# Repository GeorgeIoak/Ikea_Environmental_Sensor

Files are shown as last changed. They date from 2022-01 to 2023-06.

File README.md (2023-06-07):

# Ikea_Environmental_Sensor
Replacement Board for [Ikea Vindriktning PM2.5 Sensor](https://www.ikea.com/us/en/p/vindriktning-air-quality-sensor-60515911/)

## This board is meant as a complete replacement for the board rather than adding in a new board. 

## This board will add the following:

- ESP32-C3 processor with onboard antenna
- [Sensirion SGP40 VOC Sensor](https://www.sensirion.com/en/environmental-sensors/gas-sensors/sgp40/)
  - ~~SGP30 also works~~   SGP30 is the same package and pinout but SGP30 is a 1.8V part!
- [TI HDC1080DMBR Temp/Humidity Sensor](https://www.ti.com/store/ti/en/p/product/?p=HDC1080DMBR)
  - Same package and pinout as the [Sensirion SHT21](https://www.sensirion.com/en/environmental-sensors/humidity-sensors/humidity-temperature-sensor-sht2x-digital-i2c-accurate/)
  - The Sensirion SHT20, SHT21, and SHT25 have increasing accuracy and are pin/package compatible
  - All the the SHT2x parts have the same I2C address of 0x40 which is the same as TI HDC1080DMBR
- [QWiiC Connector](https://www.jst-mfg.com/product/pdf/eng/eSR.pdf) 1mm pitch standard I2C connector
- [Everlight ALS-PT19 Light Sensor](https://en.everlight.com/sensor/category-ambient_light_sensor/analog_ambient_light_sensor/)
- [CJT A1501WV-4P](https://www.lcsc.com/product-detail/Wire-To-Board-Wire-To-Wire-Connector_CJT-Changjiang-Connectors-A1501WV-4P_C225134.html) fits well for the 4-pin data cable on the PM2.5 sensor
- The PM2.5 Sensor has a fan with a 2-pin power connector on it. After testing many different samples the [CAX 1.25-2A](https://www.lcsc.com/product-detail/Wire-To-Board-Wire-To-Wire-Connector_CAX-1-25-2A_C722594.html) has a good fit.
  - The [CAX 1.25T-2A](https://www.lcsc.com/product-detail/Wire-To-Board-Wire-To-Wire-Connector_CAX-1-25T-2A_C722633.html) looks and fits the same. Not sure what the difference is.
  - The CAX parts seem to maybe be a knock off of the [Boom Precision Electric 1.25T-2A](https://www.lcsc.com/product-detail/Wire-To-Board-Wire-To-Wire-Connector_BOOMELE-Boom-Precision-Elec-1-25T-2A_C10819.html) but I didn't get samples to verify

For the existing PM2.5 Sensor I decided to add power control for the fan so new code to control the speed of the fan as well as when to turn it on. There is a level shifter between the PM2.5 communication header and the ESP32 since the fan operates at 5V and the ESP32 operates at 3.3V

I kept a USB C connector for the power but since the ESP32-C3 has embedded USB I connected D+/D- so you can program and communicate with the board over USB. As a backup I also included a UART header.

I kept the LEDs on the back of the board and placed them in the same locations so you can still use them as a visual status of the sensor.

I did some initial testing with test code and everything appears to be working as expected but the complete software package has not been developed yet, life keeps getting in the way.

## The PM2.5 Sensor headers are too close to each other, the cables won't both plug in
## The USB C connector has too wide of a base so it doesn't quite fit into the hole in the case. Need to find a slimmer connector and it needs to be all the way at the edge of the board

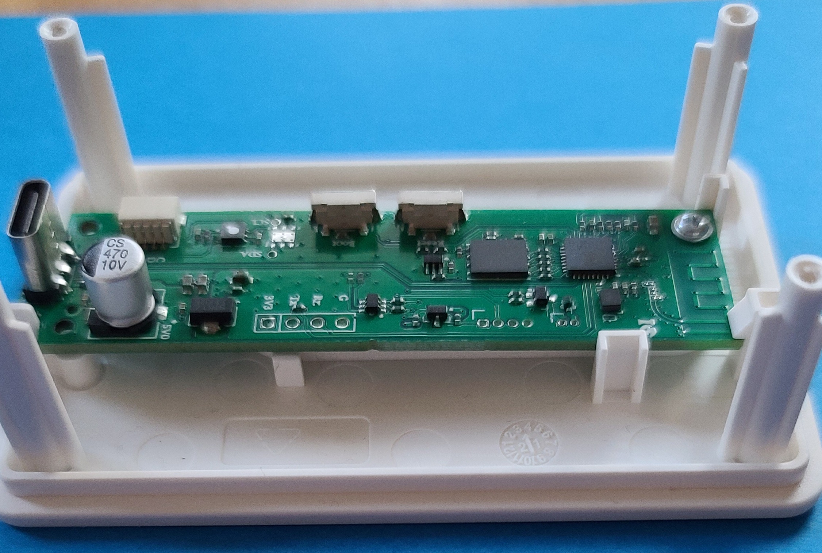
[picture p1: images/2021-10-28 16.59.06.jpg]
Prototype Prototype Fit


## Some useful links to additional information:

- https://github.com/pulsar256/vindriktning_esphome
- https://blakadder.com/vindriktning-tasmota/

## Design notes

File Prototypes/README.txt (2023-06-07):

* I designed in a 40MHz Oscillator in a 2.0 x 1.6 package but selected the wrong JLCPCB part.

  -- JLCPCB Part C213412, KDS Daishinku 1ZNA16000AB0P in a SMD2520 package
  -- Correct Part is a ECS ECS-TXO-2016-33-400-TR
  -- I bought 20pcs of Abracon EBRA53L2H-40.000M on 11/26/21 from Arrow

* The pi filter for the antenna works better with no caps mounted.

* The series resistor for the light sensor is too high
  -- R30 is 10kΩ but with 5.0V on the source the Vout is ~4.8V in bright light
  -- Changing to 1.0kΩ keeps Vout less than 3.0V
  -- Should monitor voltage once the board is in the enclosure and adjust R30

2023/06/07

* The connectors for the PM2.5 sensor were checked for fit
  -- The CAX 1.25-2A works well for the 2-pin power connector
  -- The CJT A1501WV-4P works for the 4-pin data cable
  -- There needs to be more space between these 2 connectors since the 
     cable housings are wider than the header footprint

* The USB C Connector doesn't line up with the hole in the enclosure
  -- The USB C connector needs to be closer to the board edge
  -- It's currently ~1.7mm away from the board edge and needs to be < 1mm
  -- GCT USB4160-03-0070-C looks to be slim enough, https://gct.co/connector/usb4160

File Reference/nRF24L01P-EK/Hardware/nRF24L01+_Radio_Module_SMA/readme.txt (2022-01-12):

Content of production file folders:

The folders contain:
/BOM/
	Bill of material file (*.xls)

PCB.zip
	Production files for PCB. These files are exactly the same as the "nRF24L01 Radio Module SMA" used in the nRF24L01 Development kit. Please reuse PCB if the nRF24L01 Development kit has been produced earlier.
		
/Schematics/
	Schematics file (*.pdf)

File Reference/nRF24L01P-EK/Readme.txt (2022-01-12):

This readme file describes the content of the archive file "nRF24L01P-EK.zip"

Folder "Documents" contains all available documents related to the nRF24L01+ Evaluation Kit
Folder "Firmware" contains the source code for the firmware that runs on the MCU in the nRF24L01+ Evaluation kit.
Folder "Software" contains the setup file for the Windows XP compatible program "nRF24L01+ Evaluation and Configuration"
Folder "Hardware" contains the gerber files for the RF modules that comes with the nRF24L01+ Evaluation kit

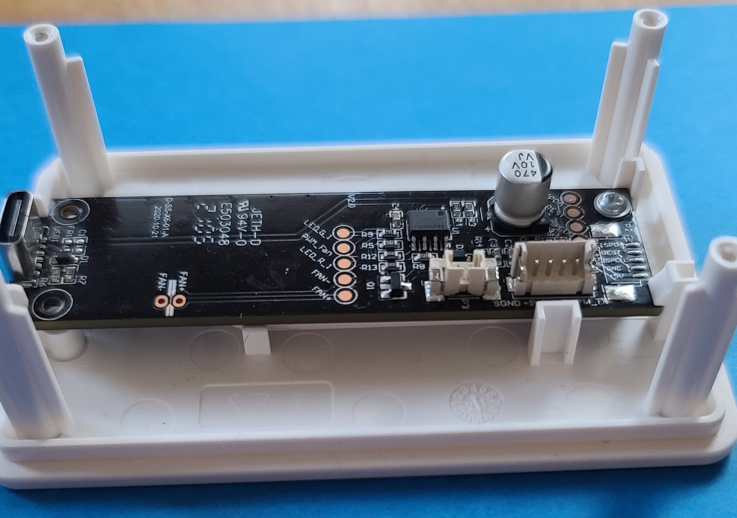
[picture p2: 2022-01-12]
images/2021-10-28 16.56.24.jpg

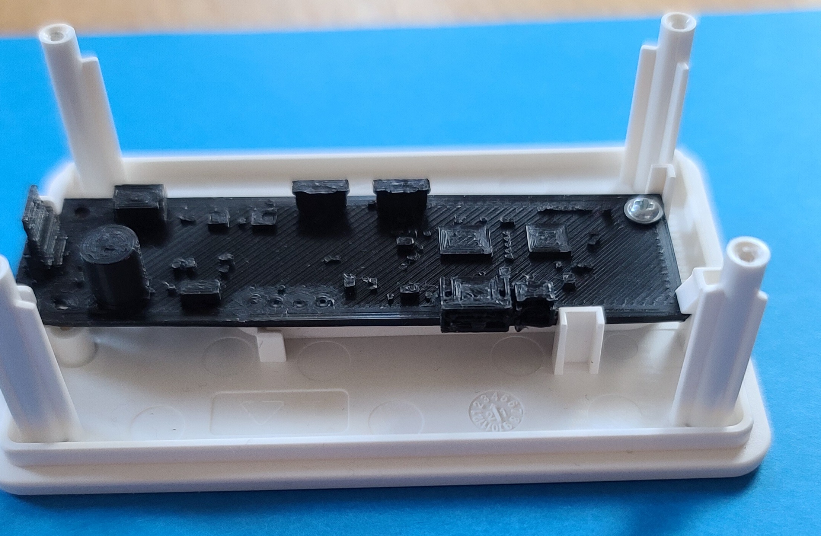
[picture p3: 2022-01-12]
images/2021-10-28 16.55.03.jpg

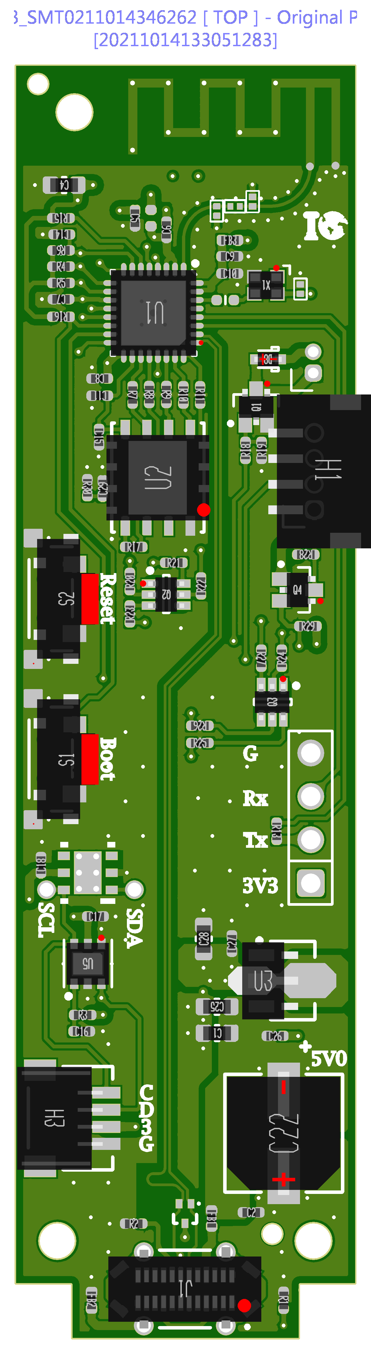
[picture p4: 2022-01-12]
Prototypes/Produce_DanZhi.SMT_Original_Snapshot.Top.2254590A_Y13.SMT0211014346262.png

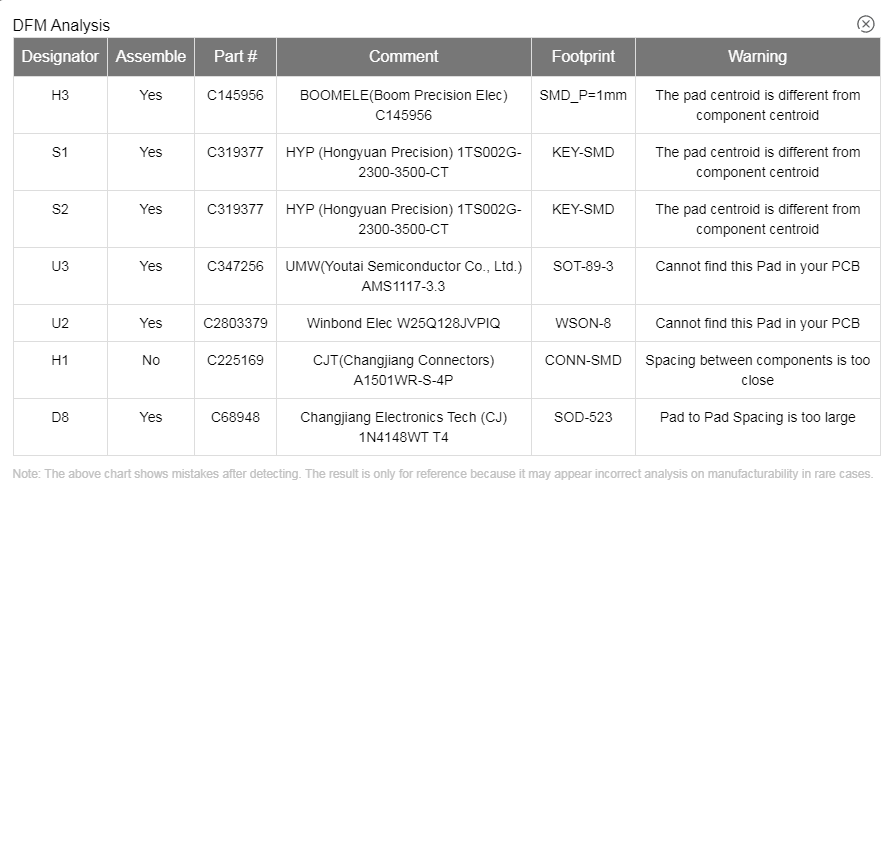
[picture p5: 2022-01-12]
Prototypes/JLCPCB_DFM.png

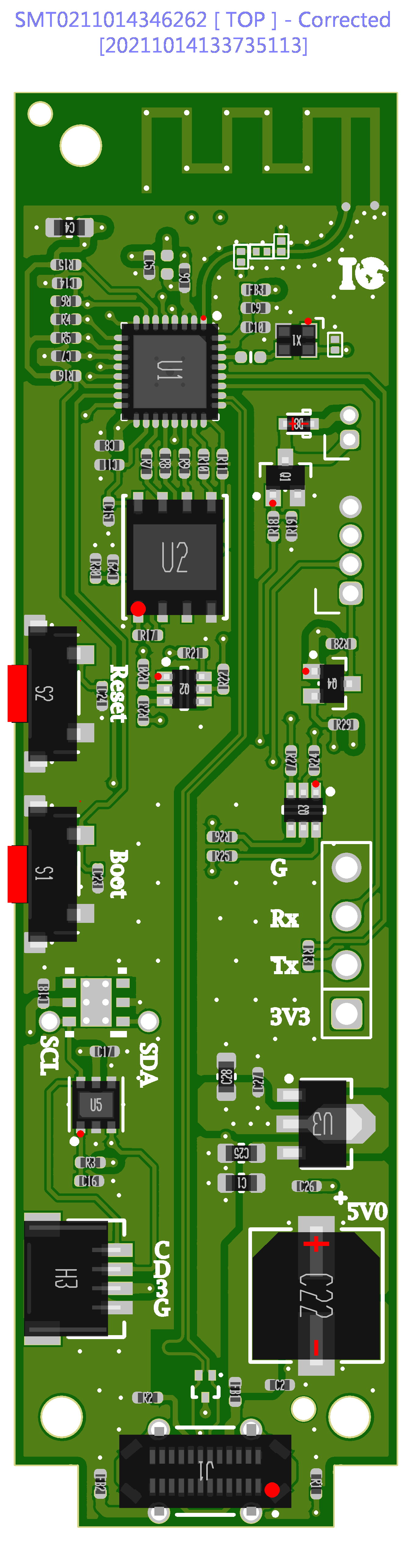
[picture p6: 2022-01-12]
Prototypes/Produce_DanZhi.SMT_Snapshot.Top.2254590A_Y13.SMT0211014346262.png

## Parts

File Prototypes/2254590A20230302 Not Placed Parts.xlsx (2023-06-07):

Designator | Comment | Footprint | Quantity
C13 | 100n | C_0201 | No part matched | 1
C19 | 100n | C_0201 | No part matched | 1
U4 | HDC1080DMBR | DMB0006A | No part matched | 1
R12 | 0R | R_0402-N | No part matched | 1
H2 | PMFan | HDR1x2_1.25mm_RA_TH | No part matched | 1
U6 | TPD2EUSB30A | DRT3 | No part matched | 1
L1 | 2.0nH | FB_0402-NIC | No part matched | 1
C12 | 100n | C_0201 | No part matched | 1
L2 | 2.0nH | L_0201 | No part matched | 1
D7 | LightSensor | XDCR_ALS-PT19-315C/L177/TR8 | BOM and specified SMT Aseembly layer does not match | 1
D3 | 0603Green | D_0603 | BOM and specified SMT Aseembly layer does not match | 1
D4 | 0603Red | D_0603 | BOM and specified SMT Aseembly layer does not match | 1
D2 | 0603Orange | D_0603 | BOM and specified SMT Aseembly layer does not match | 1
D5 | 0603Orange | D_0603 | BOM and specified SMT Aseembly layer does not match | 1
PCB? | PCB | LOGO-GIO | BOM and specified SMT Aseembly layer does not match | 1
D6 | 0603Green | D_0603 | BOM and specified SMT Aseembly layer does not match | 1
D1 | 0603Red | D_0603 | BOM and specified SMT Aseembly layer does not match | 1

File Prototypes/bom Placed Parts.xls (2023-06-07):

Comment | Designator | Footprint | JLCPCB Part #
10n |  | C_0402_N | C1524
4R7 |  | R_0402-N | C25121
100uF,35V |  | CAP_6.6x6.6 | C116423
QWiiC |  | JSTSM04B-SRSS-TB | C145956
100n | null,null,null,null,null,null,null,null,null,null,null | C_0402_N | C307331
SGP40-D-R4 |  | SGP40_SEN-M | C514454
W25Q128JVPIQ |  | WSON_8 | C2803379
1N4148 |  | SOD-523 | C68948
BOOT | null,null | SW_122514 | C319377
2k20 | null,null,null,null,null,null,null | R_0402-N | C149906
40.0MHz |  | XTAL_2.0mmx1.6mm | C213412
10u | null,null,null,null | 0603X90 | C96446
300R | null,null,null | FB_0402-NIC | C76886
AZ1117CR-3.3 |  | SOT89-150P410X160-3N | C347256
10k0 | null,null,null,null,null,null,null,null | R_0402-N | C25744
USB4070-30-C |  | USB_C_GCT_USB4070-30-C_REVC5 | C168703
1u | null,null,null,null,null,null | C_0402_N | C237173
499R | null,null,null,null,null | R_0402-N | C137970
33R0 | null,null,null,null,null | R_0402-N | C25161
ESP32-C3 |  | QFN-32_5x5 | C2838500
5k10 | null,null | R_0402-N | C25905
BC857BS | null,null | SOT363_N | C8654
PM1006 |  | HDR1x4_1.5mm_RA_TH | C225169
BSS138W-7-F | null,null | SOT323 | C24553

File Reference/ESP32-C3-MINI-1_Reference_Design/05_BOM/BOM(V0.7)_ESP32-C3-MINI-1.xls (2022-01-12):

BOM(V0.7)_ESP32-C3-MINI-1
Item | Quantity | Reference | Value | Package | ICs | Description | Notes
1 | 1 | C1,C2 | TBD | C0201 | Capacitor | Ceramic Capacitors | Defined by RF Test
3 | 1 | C4 | 10 nF / 10 V (10%) | C0201 | Capacitor | Ceramic Capacitors
4 | 2 | C3, C11 | 1 uF / 6.3 V (20%) | C0201 | Capacitor | Ceramic Capacitors
5 | 1 | C5 | 10 uF / 6.3 V (20%) | C0402 | Capacitor | Ceramic Capacitors
6 | 4 | C6, C7, C10, C12 | 0.1 uF / 10 V (10%) | C0201 | Capacitor | Ceramic Capacitors
7 | 1 | C8 | TBD | C0201 | Capacitor | Ceramic Capacitors | Defined by RF Test
8 | 1 | C9 | TBD | C0201 | Capacitor | Ceramic Capacitors | Defined by RF Test
9 | 1 | L2 | TBD | L0201 | Inductor | Inductor | Defined by RF Test
10 | 1 | L1 | 2.0 nH, ±0.1 nH, 450 mA | L0201 | Inductor | Inductor
11 | 1 | R1 | TBD | R0201 | Inductor | Inductor | Defined by RF Test
12 | 1 | R2 | 499 Ω (1%), 1/20 W | R0201 | Resistor | Chip Resistors
14 | 1 | D1 | TVS Diode, Bi-Direction, 3.3V | SOD882 | ESD / TVS | TVS Diode, 3.3 V
15 | 1 | U1 | 40 MHz, ± 7 ppm, 15 pF, 100 uW | XTAL3225 | Crystal | 40MHz Crystal
16 | 1 | U2 | ESP32-C3FH4/N4, Wi-Fi + BT + MCU + 4 MB Flash | QFN32_0P5_5 | Chip | Wi-Fi + BT + MCU + Flash
17 | 1 | Shield Box | Shield Box Size: 11.95 * 9.95 * 1.6 mm, T = 0.15 mm, Material: C7701R-H | - | - | -
18 | 1 | PCB | ESP32-C3-MINI-1 V1.1, 4L, 13.2 mm * 16.6 mm * 0.8 mm, Halogen-free, Matte black for Solder mask and white for silkscreen, immersion gold and 50 Ω impedance control. | - | - | -
*Please be noted that C8, C9 and L2 are recommended to use Murata for good quality and accuracy.

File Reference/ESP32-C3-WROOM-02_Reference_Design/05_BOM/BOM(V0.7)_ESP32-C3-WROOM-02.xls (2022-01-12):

BOM(V0.7)_ESP32-C3-WROOM-02
Item | Quantity | Reference | Value | Package | ICs | Description | Notes
1 | 1 | C1, C2 | TBD | C0201 | Capacitor | Ceramic Capacitors | Defined by RF Test
2 | 2 | C3, C11 | 1 uF / 6.3 V (20%) | C0201 | Capacitor | Ceramic Capacitors
3 | 1 | C4 | 10 nF / 10 V (10%) | C0201 | Capacitor | Ceramic Capacitors
4 | 1 | C5 | 10 uF / 6.3 V (20%) | C0402 | Capacitor | Ceramic Capacitors
5 | 4 | C6, C7, C10, C12 | 0.1 uF / 10 V (10%) | C0201 | Capacitor | Ceramic Capacitors
6 | 1 | C8 | TBD | C0201 | Capacitor | Ceramic Capacitors | Defined by RF Test
7 | 1 | C9 | TBD | C0201 | Capacitor | Ceramic Capacitors | Defined by RF Test
8 | 1 | L2 | TBD | L0201 | Inductor | Inductor | Defined by RF Test
9 | 1 | L1 | 2.0 nH, ± 0.1 nH, 450 mA | L0201 | Inductor | Inductor
10 | 1 | R1 | TBD | R0201 | Inductor | Inductor | Defined by RF Test
11 | 1 | R2 | 499 Ω (1%), 1/20 W | R0201 | Resistor | Chip Resistors
12 | 5 | R3, R4, R5, R6, R7 | 100 Ω (5%), 1/20 W | R0201 | Resistor | Chip Resistors
13 | 1 | D1 | TVS Diode, Bi-Direction, 3.3V | SOD882 | ESD / TVS | TVS Diode, 3.3 V
14 | 1 | U1 | 40 MHz, ± 7 ppm, 15 pF, 100 uW | XTAL3225 | Crystal | 40MHz Crystal
15 | 1 | U2 | ESP32-C3, Wi-Fi + BT + MCU | QFN32_0P5_5_B | Chip | Wi-Fi + BT + MCU
16 | 1 | U3 | 2.7 ~ 3.6 V, 32 Mbit, Standard&Dual&Quad SPI Flash | SOP8_1P27_6P6 | Chip | 3.3 V SPI FLASH
17 | 1 | Shield Box | Shield Box Size: 15.7 mm * 12.37 mm * 2.4 mm, T = 0.15 mm | - | - | -
18 | 1 | PCB | ESP32-C3-WROOM-02 V1.6, 4L, 18 mm * 20 mm * 0.8 mm, Halogen-free, Matte black for Solder mask and white for silkscreen, immersion gold and 50 Ω impedance control. | - | - | -
*Please be noted that C8, C9 and L2 are recommended to use Murata for good quality and accuracy.

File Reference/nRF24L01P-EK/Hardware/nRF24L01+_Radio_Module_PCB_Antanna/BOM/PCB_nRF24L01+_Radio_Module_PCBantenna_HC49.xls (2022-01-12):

Part | Designator | Footprint | Description
22pF | C1 | 0402 | NPO, +/- 5%, 50V
22pF | C2 | 0402 | NPO, +/- 5%, 50V
2.2nF | C3 | 0402 | X7R, +/- 10%, 50V
4.7pF | C4 | 0402 | NPO, +/- 0.25 pF, 50V
1.5pF | C5 | 0402 | NPO, +/- 0.1 pF, 50V
1.0pF | C6 | 0402 | NPO, +/- 0.1 pF, 50V
33nF | C7 | 0402 | X7R, +/- 10%, 50V
1nF | C8 | 0402 | X7R, +/- 10%, 50V
10nF | C9 | 0402 | X7R, +/- 10%, 50V
CON8 | J1 | 2,54mm pitch
8.2nH | L1 | 0402 | chip inductor +/- 5%
2.7nH | L2 | 0402 | chip inductor +/- 5%
3.9nH | L3 | 0402 | chip inductor +/- 5%
1M | R1 | 0402 | +/-5% (or better)
22K | R2 | 0402 | +/- 1 %
nRF24L01+ | U1 | QFN20L/5x5
16MHz | X1 | HC49 | Total tolerence +/-60ppm, CL=12pF

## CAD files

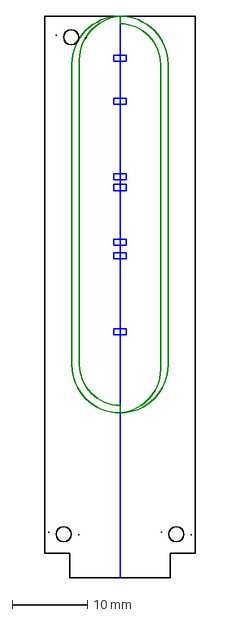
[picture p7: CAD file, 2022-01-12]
Reference/Board Outline.dxf
20.0 x 74.8 mm

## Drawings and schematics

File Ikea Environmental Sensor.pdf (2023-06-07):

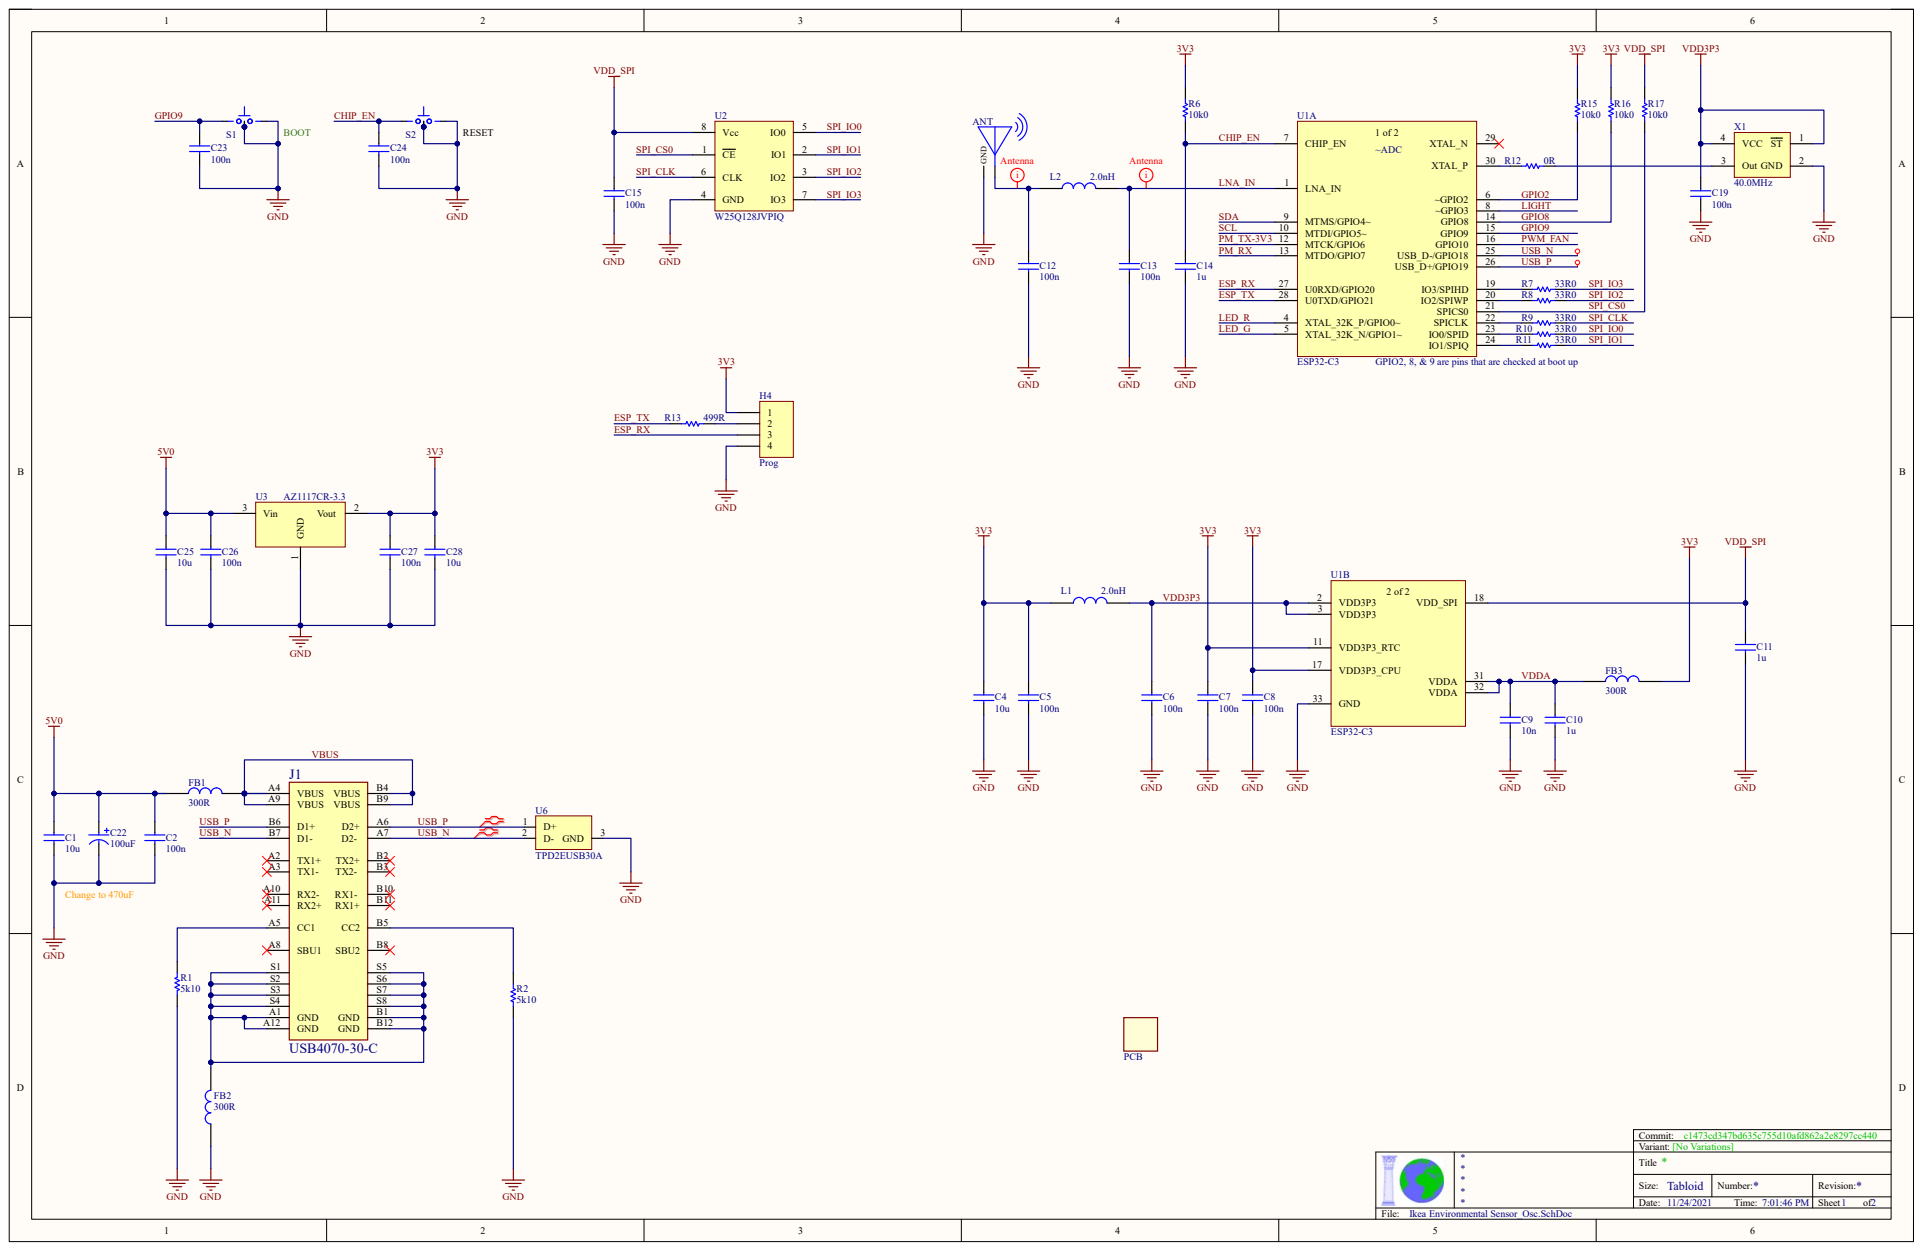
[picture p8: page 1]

GPIO2, 8, & 9 are pins that are checked at boot up

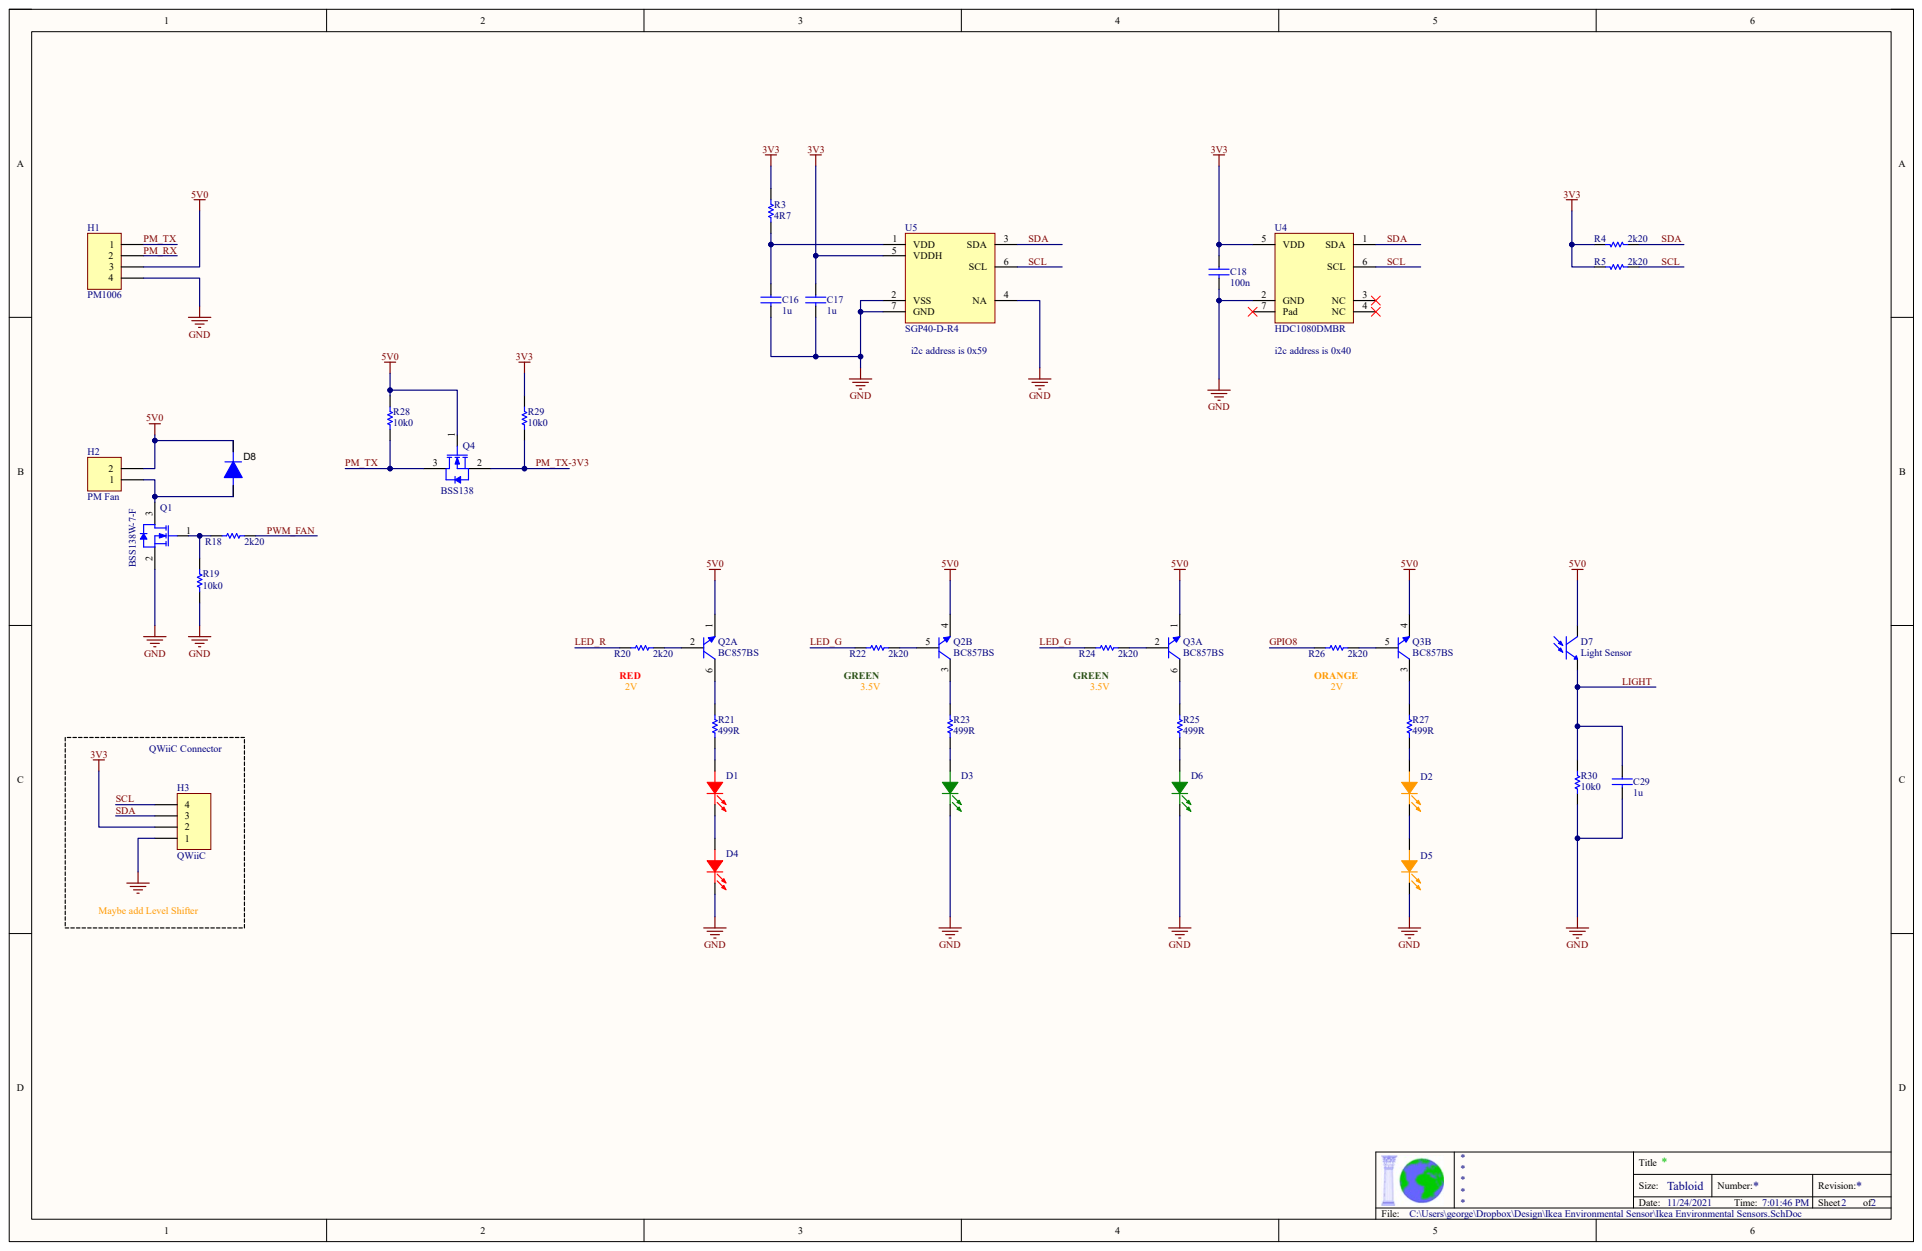
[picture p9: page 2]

Maybe add Level Shifter

C:\Users\george\Dropbox\Design\Ikea Environmental Sensor\Ikea Environmental Sensors.SchDoc

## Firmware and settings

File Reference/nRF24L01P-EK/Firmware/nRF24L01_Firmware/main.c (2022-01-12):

 /** @file main.c
 *
 * @author Runar Kjellhaug
 *
 * @compiler This program has been tested with Keil C51 V7.50.
 *
 * @copyright
 * Copyright (c) 2005 Nordic Semiconductor. All Rights Reserved.
 *
 * The information contained herein is confidential property of Nordic Semiconductor. The use,
 * copying, transfer or disclosure of such information is prohibited except by express written
 * agreement with Nordic Semiconductor.
 * @endcopyright
 *
 * $Date: 3.03.06 10:52 $
 * $Revision: 60 $
 *
 */
//  Global defines & includes
#include <cygnal\c8051F320.h>
#include "include\defines.h"
#include "include\usb.h"
#include "include\fwupgrade.h"
#include "include\F320_FlashPrimitives.h"
#include "include\nRF_API.h"
#include "include\ADC.h"
#include "include\TestApp.h"
#include "include\LL_API.h"
#include "include\Protocol_API.h"

code const UINT FW  = FW_VERSION;                                     // Firmware version, const..

BYTE xdata RX_buffer[USB_RX_SIZE];                                    // Last packet received from host

BYTE xdata TX_buffer[USB_TX_SIZE];                                    // Next packet to sent to host

BYTE xdata TX_pload[TX_PLOAD_MAX_WIDTH];                              // TX payload buffer
BYTE xdata RX_pload[RX_PLOAD_MAX_WIDTH];                              // RX payload buffer

BYTE xdata Table_Ptr;                                                 // Pointer for Freq_table lookup
BYTE xdata Freq_table[FREQ_TABLE_SIZE] = {2,27,52,7,32,57,12,37,
                                         62,17,42,67,22,47,72,77};    // Freq Agility table, predefined

BYTE xdata Trans_Ctrl[TRANS_PARAMS];                                  // Transmission Control bytes
BYTE xdata Freq_agil[NUM_OF_PIPES];                                   // Freq Agility On/Off for pipe.n
BYTE xdata TX_Addr[TX_ADDR_WIDTH];                                    // TX address buffer
BYTE xdata RX_pload_length[NUM_OF_PIPES];                             // holds #of bytes for pipe 0..5
BYTE xdata TX_pload_width;                                            // TX payload width variable
BYTE xdata Freq_Agil_Status;                                          // Variable that holds status of frequency agility
BYTE xdata Freq_Agil_Pipe;

BYTE xdata Button_Mode = 0;
BYTE xdata Button;                                                    // Variable that holds button index for communication
BYTE xdata SW1_Released;

//Status bytes
BYTE USB_Rx_Comp = 0;                                                 // Indicates new USB frame received
BYTE SPI_Mode = 0;                                                    // Select between HW and SW SPI
BYTE Sweep_Mode = 0;                                                  // Sweep mode on/off
BYTE Com_Mode = 2;                                                    // Communication mode on/off
BYTE IRQ_Source = 0x00;                                               // Indicates IRQ source from nRF24L01
BYTE Sweep_Progress;
BYTE Test_Mode;
BYTE Agil_Timeout;
BYTE LinkStatus[2];                                                   // Link status array, status & channel
BYTE LinkStat,LastStat;
BYTE TX_Update;
BYTE RX_Timeout;
UINT Link_Loss_Delay;                                                 // Link Loss dalay variable
BYTE Link_Loss_Status;

BYTE RX_pipe;                                                         // store RX_FIFO pipe number
BYTE byte_ctr;

// Variables used for 'Sweep_Mode'
BYTE sw_low,sw_high,next_ch;
BYTE Sweep_Time_Ctr = 0;

BYTE Trans_Tmr,Trans_Tmr_Ctr = 0;                                     // Variables for trans timer comm mode
BYTE Timer_Mode;                                                      // Variable for timer mode
BYTE Try_Ctr;                                                         // Try Counter variable
BYTE Pipe_Length;                                                     // Current RX pipe length variable
UINT CPU_temp, RF_Vdd;
BYTE Led_Blink1,Led_Blink2,Led_Blink3,Led_Blink4;
BYTE T2_State;

//--------------------------------------------------------------------
// Main Routine
//--------------------------------------------------------------------
void main(void)
{
  CPU_Init();

  while (TRUE)
  {
#ifdef _TESTMODE_
    while (!USB_Rx_Comp)                                              // wait for USB command
    {
      if(!SW1) Test_TX();                                             // Goto TX mode
      if(!SW2) Test_RX();                                             // Goto RX mode
      if(USB_SW != 0x0f)                                              // Enable SW3 = CE if USB_ID <> 0.
      {
        if(!SW3)
        {
          CE_Pin(CE_HIGH);                                            // Hold CE high while SW3 is pressed.
        }
        else 
        {
          CE_Pin(CE_LOW);                                             // Hold CE low as long as SW3 is released.
        }
      }
    }
#else
    while(!USB_Rx_Comp)                                               // wait for USB command, and prosess other operations
    {
      if(IRQ_Source)                                                  // wait for nRF24L01 interrupt
      {
      EX0 = 0;                                                        // Disable External interrupt during prosessing
      if(T2_State)
        {
          ET2 = 0;                                                    // Disable T2 interrupt
          Stop_T2();                                                  // and stop timer2
        }
        switch(IRQ_Source)
        {
          case RX_DR:                                                 // RX Data received interrupt                                          
            do
            {
              RX_pipe = L01_Read_RX_Pload(RX_pload) >> 8;             // Read current payload
              if(Freq_Agil_Pipe == RX_pipe)                           // Packet received for "expected" pipe?
              {
                Blink_Led(LED1);                                      // _DEBUG_LED_ Led1 BLINK
                LinkStatus[LINK_STATUS] = LINK_ESTABLISH;             // Indicate "Link Loss"
                LinkStatus[LINK_CHANNEL] = L01_Get_Channel();         // Insert current channel
              
                LinkStat = LINK_ESTABLISH;                            // New LinkStat
                Agil_Timeout  = CLEARED;                              // Packet received, i.e. ok
                Trans_Tmr_Ctr = CLEAR;                                // Reset frequency agility timer
              }
              else
                Blink_Led(LED2);                                      // _DEBUG_LED_ Led2 BLINK if data of other pipe
            }
            while(!(L01_Get_FIFO() & RX_EMPTY));                      // ..until FIFO empty

            L01_Clear_IRQ(MASK_RX_DR_FLAG);                           // clear RX_DR flag
          break;
          
          case TX_DS:                                                 // TX Data sent interrupt
            Blink_Led(LED1);                                          // _DEBUG_LED_ Led1 BLINK
            LinkStat = LINK_ESTABLISH;                                // set LinkStat = LINK_ESTABLISH
            Trans_Tmr_Ctr = CLEAR;                                    // reset Transmitt Timer..

            L01_Clear_IRQ(MASK_TX_DS_FLAG);                           // Clear TX_DS flag
          break;

          case MAX_RT:
          {
            Blink_Led(LED3);                                          // _DEBUG_LED_ Led3 BLINK

            if(Freq_Agil_Status)                                      // running in freq_agil mode?
            {
              if(++Table_Ptr == FREQ_TABLE_SIZE)                      // Freq_table wrapping?
              {
                Blink_Led(LED4);                                      // _DEBUG_LED_ Led4 BLINK
                Table_Ptr = CLEAR;                                    // Reset Table_Ptr to first channel,
                if(Try_Ctr++ == 3)
                {
                  LinkStat = STOP;
                }
              }
              L01_Set_Channel(Freq_table[Table_Ptr]);                 // select new channel
            }
            
            Trans_Tmr_Ctr = CLEAR;                                    // reset Transmitt Timer..
            switch(LinkStat)
            {
              case LINK_ESTABLISH:                                    // max retransmitt, but had comm on last channel
                L01_Clear_IRQ(MASK_MAX_RT_FLAG);                      // clear MAX_RT flag (nRF24L01)
              
                LinkStat = LINK_LOSS;                                 // change LinkStat state to LINK_LOSS, wait for new timeout
              break;

              case LINK_LOSS:                                         // still not connected, run channel scan..
                L01_Clear_IRQ(MASK_MAX_RT_FLAG);                      // clear MAX_RT flag (nRF24L01)
                CE_Pin(CE_PULSE);                                     // retransmitt packet
              
                LinkStat = LINK_RELOST;                               // change LinkStat state to LINK_RELOST
              break;
            
              case LINK_RELOST:
                L01_Clear_IRQ(MASK_MAX_RT_FLAG);                      // clear MAX_RT flag (nRF24L01)
                CE_Pin(CE_PULSE);                                     // retransmitt packet
              
                LinkStat = LINK_RELOST;
              break;

              case STOP:
                L01_Clear_IRQ(MASK_MAX_RT_FLAG);                      // clear MAX_RT flag
                LinkStat = LINK_ESTABLISH;                            // stop retransmission
              break;
            }
          }
          break;

          default:                                                    // ..error handler
          
          break;
        }
        IRQ_Source = CLEAR;                                           // Clear IRQ flag

        if(T2_State)
          {
            Start_T2();
            ET2 = 1;                                                  // Enable T2 interrupt only if T2 in use          
          }

        EX0 = 1;                                                      // Enable external interrupt again..
      }
      
      Check_Button_TX();

    }


#endif
    Sweep_Mode = CLEAR;                                               // Terminate Sweep_Mode
    USB_Rx_Comp = CLEAR;
    switch(RX_buffer[CMD])                                            // USB command decoder
    {
      case CSN_STATE:                                                 // Set/Reset CSN(NSS) pin
        CSN_Pin(RX_buffer[ARG]);
        TX_buffer[0] = 0;
        Block_Write(TX_buffer,1);
      break;

      case SPI_COMMAND:                                               // Writes a SPI byte
        TX_buffer[0] = SPI_RW(RX_buffer[ARG]);
        Block_Write(TX_buffer,1);
      break;

      case CE_BIT:                                                    // Set/Reset CE pin
        CE_Pin(RX_buffer[ARG]);
        
        TX_buffer[0] = 0;
        Block_Write(TX_buffer,1);
      break;

      case FW_VER:                                                    // Return current FirmWare version
        TX_buffer[0] = (BYTE)(FW>>8);                                 // Get major FW_Ver
        TX_buffer[1] = (FW & 0xff);                                   // Get minor FW_Ver
        
        Block_Write(TX_buffer, 2);
      break;

      case READ_USB_ID:                                               // Return current USB_ID switch setting
        TX_buffer[0] = USB_ID;                                        // macro; defines.h
        Block_Write(TX_buffer,1);
      break;

      case WRITE_LEDS:                                                // Set/Reset LED...
        Write_Led(RX_buffer[ARG], RX_buffer[VALUE]);
        TX_buffer[0] = 0;
        Block_Write(TX_buffer,1);
      break;

      case WR_FLASH_BLOCK:                                            // Writes 32 bytes of flash data to block 'n'
        WritePageBlock(RX_buffer[ARG], &RX_buffer[VALUE]);
        TX_buffer[0] = 0x00;
        Block_Write(TX_buffer,1);
      break;

      case RD_FLASH_BLOCK:                                            // Reads and return 32 bytes of flash block 'n'
        ReadPageBlock(RX_buffer[ARG], &TX_buffer[0]);
        Block_Write(TX_buffer, SZ_BLOCK);
      break;

      case WR_FLASH_PAGE:                                             // Writes the flash page n*256 buffer to flash
        if (RX_buffer[ARG] == 0)
          EA = 0;
        WriteFlashPage((unsigned)RX_buffer[ARG]);
        if (RX_buffer[ARG] == 0)
          EA = 1;

        TX_buffer[0] = 0x00;
        Block_Write(TX_buffer,1);
      break;

      case RD_FLASH_PAGE:                                             // Read the n*256 flash page to flash buffer
        ReadFlashPage((unsigned)RX_buffer[ARG]);
        TX_buffer[0] = 0x00;
        Block_Write(TX_buffer,1);
      break;

      case WD_RESET:                                                  // Use WatchDog reset to reset F320
        WD_Reset();
      break;

      case READ_LOCK_BYTE:                                            // Return Lock Byte
        TX_buffer[0] = FLASH_ByteRead(0x3dff);
        Block_Write(TX_buffer, 1);
      break;

      case SPI_SELECT:                                                // Select SPI Mode
        SPI_Init(RX_buffer[ARG]);
        TX_buffer[0] = 0;
        Block_Write(TX_buffer,1);
      break;

      case ST_FR_SWEEP_TX:                                            // Start Frequency Sweep TX[sw_low..sw_high]
        sw_high = RX_buffer[1];
        sw_low  = RX_buffer[2];
        next_ch = sw_low;                                             // Init sweep low channel
        Sweep_Mode = 1;                                               // Sweep_Mode on.
        Sweep_Progress = 1;                                           // Indicates sweep in progress
        ET2 = 1;                                                      // Enable Timer2
        TX_buffer[0] = 0;
        Block_Write(TX_buffer,1);
      break;

      case ST_FR_SWEEP_RX:                                            // Start Frequency Sweep RX[sw_low..sw_high]
        sw_high = RX_buffer[1];
        sw_low  = RX_buffer[2];
        next_ch = sw_low;                                             // init sweep low channel
        Sweep_Mode = 1;                                               // Sweep_Mode on.
        Sweep_Progress = 1;                                           // Indicates sweep in progress
        ET2 = 1;                                                      // Enable Timer2
        TX_buffer[0] = 0;
        Block_Write(TX_buffer,1);
      break;

      case STOP_SWEEP:                                                // Stop current frequency sweep
        Sweep_Mode = 0;                                               // Terminate Sweep_Mode

        TX_buffer[0] = 0;
        Block_Write(TX_buffer,1);
      break;

      case WR_TRANS_CTRL:                                             // Set TX control parameters
        Trans_Ctrl[0] = RX_buffer[ARG];
        Trans_Ctrl[1] = RX_buffer[VALUE];

        TX_buffer[0] = 0;
        Block_Write(TX_buffer,1);
      break;

      case RD_TRANS_CTRL:                                             // Return TX control parameters
        TX_buffer[0] = Trans_Ctrl[0];
        TX_buffer[1] = Trans_Ctrl[1];
        Block_Write(TX_buffer,2);
      break;

      case WR_FREQ_AGIL:                                              // Set freq. agility parameters to pipe.n variabel
        Freq_agil[RX_buffer[ARG]] = RX_buffer[VALUE];

        TX_buffer[0] = 0;
        Block_Write(TX_buffer,1);
      break;

      case RD_FREQ_AGIL:                                              // Return freq.agility parameters for pipe.n
        TX_buffer[0] = Freq_agil[RX_buffer[ARG]];
        Block_Write(TX_buffer,1);
      break;

      case WR_CH_TABLE:                                               // Write freq_table contents
        for(byte_ctr=0;byte_ctr<FREQ_TABLE_SIZE;byte_ctr++)
          Freq_table[byte_ctr] = RX_buffer[ARG + byte_ctr];

        TX_buffer[0] = 0;
        Block_Write(TX_buffer,1);
      break;

      case RD_CH_TABLE:                                               // Read freq_table data
        for(byte_ctr=0;byte_ctr<FREQ_TABLE_SIZE;byte_ctr++)
          TX_buffer[byte_ctr] = Freq_table[byte_ctr];

        Block_Write(TX_buffer,FREQ_TABLE_SIZE);
      break;

      case WR_TX_PAYLOAD:                                             // Write TX payload data
        for(byte_ctr=0;byte_ctr<RX_buffer[ARG];byte_ctr++)
          TX_pload[byte_ctr] = RX_buffer[(byte_ctr+2)];               // Load TX payload into buffer
        TX_pload_width = RX_buffer[ARG];                              // Write TX_pload witdh

        TX_buffer[0] = 0;
        Block_Write(TX_buffer,1);
      break;

      case READ_TX_PLOAD:                                             // Host read TX payload
        TX_buffer[0] = TX_pload_width;
        for(byte_ctr=0;byte_ctr < TX_pload_width;byte_ctr++)
          TX_buffer[byte_ctr+1] = TX_pload[byte_ctr];                 // Load TX_buffer with TX payload data

        Block_Write(TX_buffer, (TX_pload_width + 1));
      break;
      
      case WR_RX_PLOAD_LENGTH:                                        // Write RX payload length for pipe.n
        RX_pload_length[RX_buffer[ARG]] = RX_buffer[VALUE];
        
        TX_buffer[0] = 0;
        Block_Write(TX_buffer, 1);
      break;

      case RD_RX_PLOAD_LENGTH:                                        // Read RX payload length for pipe.n
        TX_buffer[0] = RX_pload_length[RX_buffer[ARG]];

        Block_Write(TX_buffer, 1);
      break;

      case START_COM_MODE:                                            // Start communication mode
        Com_Mode = RX_buffer[ARG];
        TX_buffer[0] = 0;
        Block_Write(TX_buffer,1);

        Start_Communication(Com_Mode);
      break;

      case READ_TEMP:                                                 // Read C8051F320 temperature
        CPU_temp = Read_Temperature();
        TX_buffer[0] = (CPU_temp >> 8);
        TX_buffer[1] = (CPU_temp & 0xff);
        Block_Write(TX_buffer,2);
      break;

      case READ_VOLT:                                                 // Read RF_Vdd voltage
        RF_Vdd = Read_RF_Vdd();
        TX_buffer[0] = (RF_Vdd >> 8);
        TX_buffer[1] = (RF_Vdd & 0xff);
        Block_Write(TX_buffer,2);
      break;

      case READ_RX_DATA:                                              // Read RX data
      break;

      case ENTER_TEST_MODE:                                           // Enter testmode
        Enter_Testmode(RX_buffer[ARG]);
        TX_buffer[0] = 0;
        Block_Write(TX_buffer,1);
      break;

      case WR_FREQ_AGILITY:                                           // Enable/ disable freq.agility
        Freq_Agil_Status = RX_buffer[ARG];

        TX_buffer[0] = 0;
        Block_Write(TX_buffer, 1);
      break;

      case RD_FREQ_AGILITY:                                           // Read freq.agility status (enabled or disabled)
        TX_buffer[0] = Freq_Agil_Status;
        Block_Write(TX_buffer, 1);
      break;

      case UPDATE_DEVICE:                                             // Command that indicates a new device update
//        Reset_L01();                                                  // Reset L01 before new update, NOT implemented
        TX_buffer[0] = 0;
        Block_Write(TX_buffer, 1);
      break;

      case STOP_COMM_MODE:                                            // Command received when "Stop Comm.. Mode" button pressed..
        IRQ_Source = CLEAR;
        ET2 = 0;                                                      // Disable T2 interrupt
        EX0 = 0;                                                      // Disable extern interrupt0, nRF24L01_IRQ
        CE_Pin(CE_LOW);                                               // CE low
        Led1 = Led2 = Led3 = Led4 = 1;                                // Clear all status Led's
        Com_Mode = 2;                                                 // Set Com_Mode = 2, idle
        
        TX_buffer[0] = 0;
        Block_Write(TX_buffer, 1);
      break;

      case RD_COMM_MODE_STAT:                                         // Return communication mode status
        TX_buffer[0] = Com_Mode;
        Block_Write(TX_buffer, 1);
      break;

      case RD_LINK_STATUS:                                            // Return Link Status to host
        TX_buffer[0] = LinkStatus[0];
        TX_buffer[1] = LinkStatus[1];
        LinkStatus[0] = LinkStatus[1] = 0;                            // Clear status after status read
        Block_Write(TX_buffer, 2);
      break;

      default:                                                        // Default switch() handler
      break;
    }

  }

}


/*********************************************
*
* Start_Communication
*
* Starts either RX or TX mode
*
*********************************************/
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

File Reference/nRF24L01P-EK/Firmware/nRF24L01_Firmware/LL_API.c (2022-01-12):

/** @file low_level.c
 *
 * @author Runar Kjellhaug
 *
 * @compiler This program has been tested with Keil C51 V7.50.
 *
 * @copyright
 * Copyright (c) 2005 Nordic Semiconductor. All Rights Reserved.
 *
 * The information contained herein is confidential property of Nordic Semiconductor. The use,
 * copying, transfer or disclosure of such information is prohibited except by express written
 * agreement with Nordic Semiconductor.
 * @endcopyright
 *
 * $Date: 2.03.06 15:23 $
 * $Revision: 41 $
 *
 */
#include <cygnal\c8051F320.h>
#include "include\LL_API.h"
#include "include\usb.h"
#include "include\nRF_API.h"
#include "include\ADC.h"
#include "include\Protocol_API.h"
#include "include\defines.h"

extern BYTE xdata TX_pload[TX_PLOAD_MAX_WIDTH];         // TX payload buffer
extern BYTE xdata Freq_table[FREQ_TABLE_SIZE];          // Freq Agility table
extern BYTE xdata Freq_agil[NUM_OF_PIPES];              // Freq Agility On/Off for pipe.n
extern BYTE xdata Trans_Ctrl[TRANS_PARAMS];             // Transmission Control bytes
extern BYTE xdata RX_pload_length[NUM_OF_PIPES];        // holds #of bytes for pipe 0..5
extern BYTE xdata TX_pload_width;                       // TX payload width variable
extern BYTE xdata TX_buffer[USB_TX_SIZE];               // Next packet to sent to host
extern BYTE LinkStatus[2];
extern BYTE LinkStat, LastStat;                         // Link Status bytes
extern BYTE xdata Button, SW1_Released;
extern BYTE xdata Button_Mode;

extern BYTE Com_Mode;
extern BYTE SPI_Mode;
extern BYTE Led_Blink1,Led_Blink2;
extern BYTE Led_Blink3,Led_Blink4;
extern UINT Link_Loss_Delay;
extern BYTE Try_Ctr;

code const BYTE P0_ADDR[4] =  {0xE7,0xE7,0xE7,0xE7};    // Default P0 address
code const BYTE P1_ADDR[4] =  {0xC2,0xC2,0xC2,0xC2};    // Default P1 address

void CPU_Init(void)
{
BYTE counter;

  PCA0MD &= ~0x40;                                      // Disable Watchdog timer
  Port_Init();
  SPI_Init(HW_MODE);                                    // Default HW SPI Mode
  ADC_Init();                                           // Init & enable ADC
  OSCICN |= (0x03);                                     // SYSCLK = OSC/1, i.e. 12MHz
  IT01CF = 0x05;                                        // Assign /INT0 to P0.5 pin
  IT0 = 1;                                              // Edge trigged interrupt0 (nRF24L01 IRQ)
  
  Init_T0();                                            // Init Timer0..
  Start_T1();                                           // Init Timer1
  Init_T2();                                            // Start Timer2
  
  USB_Initialize();
  REG0CN |= 0x80;                                       // Internal Voltage Regulator Disabled
  
  TX_pload_width = 16;
  for(counter=0;counter<TX_pload_width;counter++) 
    TX_pload[counter] = counter+2;                      // Init TX_payload buffer
  
  Freq_agil[PIPE0] = 8;                                 // Init Freq_agil for pipe0; 8ms
  for(counter=1;counter<6;counter++)                    
    Freq_agil[counter] = 0;                             // the rest is disabled
  
  for(counter=0;counter<6;counter++)                    // Init RX_pload_length for all pipe's
    RX_pload_length[counter] = 0x10;                    // Default 16 bytes
  
  Trans_Ctrl[0] = 0;                                    // Default trans ctrl; Timer Mode
  Trans_Ctrl[1] = 5;                                    // Default timer: 5ms
  Com_Mode = 2;                                         // Default, communication mode disabled
}

//-------------------------
// Port_Init
//-------------------------
// Port Initialization
// - Configure the Crossbar and GPIO ports.
//
void Port_Init(void)
{

  P0MDOUT = P0_DOUT;                                    // Port0..3 Mode & Values, see. "low_level.h" for details
  P1MDOUT = P1_DOUT;
  P2MDOUT = P2_DOUT;
  P2MDOUT = P2_DOUT;

  P0MDIN  = P0_DIN;
  P1MDIN  = P1_DIN;
  P2MDIN  = P2_DIN;
  P3MDIN  = P3_DIN;

  P0      = P0_INIT;
  P1      = P1_INIT;
  P2      = P2_INIT;
  P3      = P3_INIT;

  XBR0    = XBAR0;                                      // XBR0.1 => SPI Enabled
  XBR1    = XBAR1;                                      // Enable Crossbar
}


void WD_Reset(void)                                     // "Reset" µC
{
  USB_Disable();
  ET2 = 0x00;
  EX0 = 0x00;
  PCA0CPL4  = 0xff;
  PCA0MD    = 0x00;
  PCA0MD   |= 0x40;

  while(1);
}


void Init_T0(void)
{
  TH0 = 253;                                            // Init T0 reload value, 12µs
  TL0 = 253;                                            // Init T0 start value..
  CKCON |= 0x02;                                        // T0 = SCK/48
  TMOD |= 0x02;                                         // T0:Mode2, 8-bit reload timer.
  ET0 = 1;                                              // Enable timer0 interrupt
}

void Start_T1(void)
{
  TH1 = 194;                                            // Init T1 reload value, 250µs
  TL1 = 194;                                            // Init T1 start value..
  CKCON |= 0x02;                                        // T1 = SCK/48
  TMOD |= 0x20;                                         // T1:Mode2, 8-bit reload timer.
  ET1 = 1;                                              // Enable timer1 interrupt
  TR1 = 1;                                              // Start timer1...
}


void Init_T2(void)                                     // Init Timer2 for 1ms intervals
{
  TMR2H = 0x00;                                         // T2 CounterH = 0
  TMR2L = 0x00;                                         // T2 CounterL = 0
  TMR2RLH = 0xfc;                                       // T2 ReloadH
  TMR2RLL = 0x18;                                       // T2 ReloadL
//  TMR2CN  = 0x04;                                       // T2 Enabled
}

void Start_T2()                                         // Start Timer2
{
  TMR2CN |= 0x04;                                       
}

void Stop_T2()                                          // Stop Timer2 and clear T2 counter
{
  TMR2CN &= ~0x04;
//  TMR2H = 0x00;                                         // T2 CounterH = 0
//  TMR2L = 0x00;                                         // T2 CounterL = 0

}

void Write_Led(BYTE led, BYTE state)                    // Set/reset LEDn
{
  switch(led)
  {
    case LED1:
      Led1 = !state;                                    // Output value to LED1
    break;

    case LED2:
      Led2 = !state;                                    // Output value to LED2
    break;

    case LED3:
      Led3 = !state;                                    // Output value to LED3
    break;

    case LED4:
      Led4 = !state;                                    // Output value to LED4
    break;
  }

}
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

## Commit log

2021-09-29 Project Ikea Environmental Sensor was created from the template.
    [Ikea Environmental Sensor.PrjPcb, PCB1.PcbDoc, Sheet1.SchDoc]
2021-10-10 Before rework to move connectors
    [Ikea Environmental Sensors.SchDoc]
2021-10-11 Matched USB trace lengths, just because I felt like it
    [Ikea Environmental Sensor.PrjPcb]
2021-10-11 Added teardrops and GND stitching
2021-10-13 Layout finished but PM connectors may be in a bad location
    [Ikea Environmental Sensor.PrjPcb]
2021-10-14 I released this to JLCPCB on 10/13/21
    [Ikea Environmental Sensor.PrjPcb, Ikea Environmental Sensor_Osc.SchDoc]
2021-11-06 Update supplier links Create Draftsman Document
    [Ikea Environmental Sensor.PrjPcb, Ikea Environmental Sensor_Osc.SchDoc, Ikea Environmental Sensors.SchDoc]
2022-01-12 Clean up and add references
    [01_DesignBlock.SchDoc, 02_ESP32-C3-MINI-1.SchDoc, 02_ESP32-C3-WROOM-02.SchDoc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]
2022-01-14 SGP30 Won't Work
    Max input voltage on SGP30 is only 1.98V
2022-04-02 Added Schematic PDF
2023-06-07 Added info on 1.25mm pitch
    The PM2.5 sensor unit has a Wangsheng DA Technology Co., Ltd. Model 3010 fan attached to it and I found the mating 2-pin connector used to power the fan.
2023-06-07 Added Notes on Fit
    Found the right connectors for the PM2.5 sensor but I placed them too close to each other on the PCB.
    The USB C connector is ~1mm from the board edge, IKEA's is less than 0.5mm
2023-06-07 after prototype updates
    [2254590A20230302 Not Placed Parts.xlsx, bom Placed Parts.xls]
